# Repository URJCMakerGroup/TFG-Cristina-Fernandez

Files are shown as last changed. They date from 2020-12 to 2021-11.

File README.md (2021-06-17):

# TFG Cristina Fernández

## Project documentation in wiki: https://github.com/URJCMakerGroup/TFG-Cristina-Fernandez/wiki

## License

Hardware License: [CERN-OHL-S 2.0](cern_ohl_s_v2.txt)

Software License: [LGPL 3.0 or later](License.md)

Documentation License: [CC BY 4.0](https://creativecommons.org/licenses/by/4.0/)

licence summary

ES000021

This project has been certified as [open source hardware](https://certification.oshwa.org/es000021.html) by the [Open Source Hardware Association](https://www.oshwa.org/). 

## Organización de las carpetas:

- FreeCAD: archivo creado por FreeCAD
- Images: Imágenes de la documentación
- comps: copia del reposiorio fcad-comps de Felipe Machado
- img: imágenes de las piezas diseñadas en 3D
- src: código fuente
- step: archivo de modelo 3D formateado en STEP
- stl: archivo de modelo 3D en formato estándar que puede ser leído epor múltiples aplicaciones CAD

## Piezas:

- ### [Soporte Eje Y](https://github.com/URJCMakerGroup/TFG---Cristina---Fernandez/blob/main/src/base_class.py)

  <p align="center">
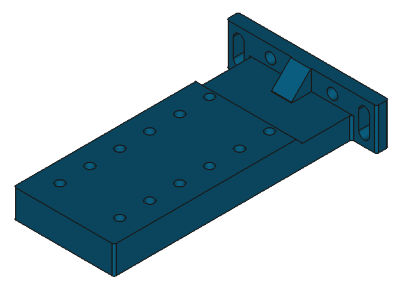
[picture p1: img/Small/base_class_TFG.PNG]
    
  </p>

- ### [Soporte motor](https://github.com/URJCMakerGroup/TFG-Cristina-Fernandez/blob/main/src/NemaMotorHolder_class.py)

<p align="center">
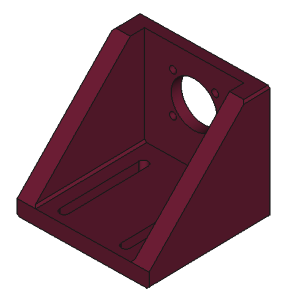
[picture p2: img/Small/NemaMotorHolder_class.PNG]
  
</p>

- ### [Soporte tuerca husillo](https://github.com/URJCMakerGroup/TFG---Cristina---Fernandez/blob/main/src/board_class.py)

<p align="center">
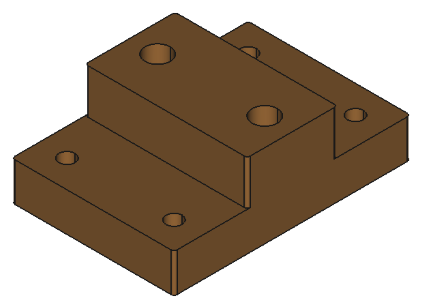
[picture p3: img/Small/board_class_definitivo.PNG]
  
</p>

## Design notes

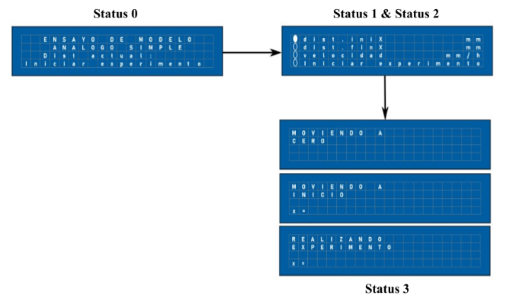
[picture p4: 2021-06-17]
Images/Small/Pantalla_LCD.PNG

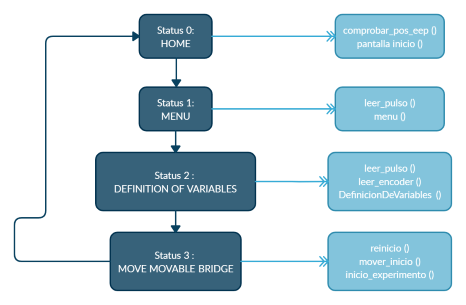
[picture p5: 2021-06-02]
Images/Small/Esquema_funcionamiento_mesa_modelado.png

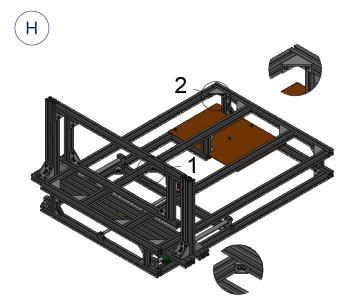
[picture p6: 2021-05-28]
Images/Small/EtapaH.PNG

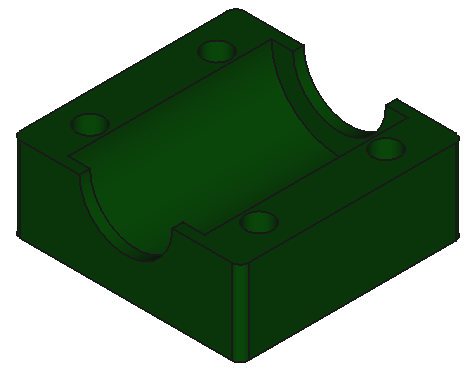
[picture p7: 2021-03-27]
img/Big/Soporte_Cojinete_inferior.PNG

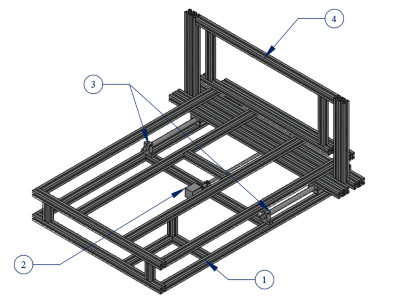
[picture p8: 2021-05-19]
Images/Small/Mesa_modelado_small.png

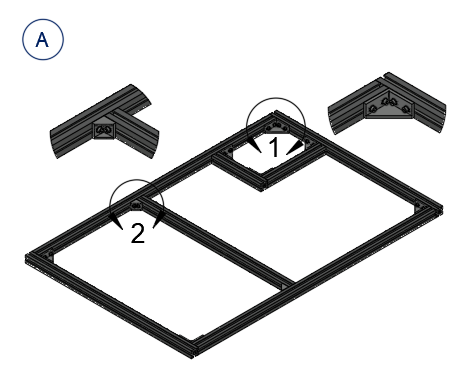
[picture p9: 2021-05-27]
Images/Big/EtapaA.PNG

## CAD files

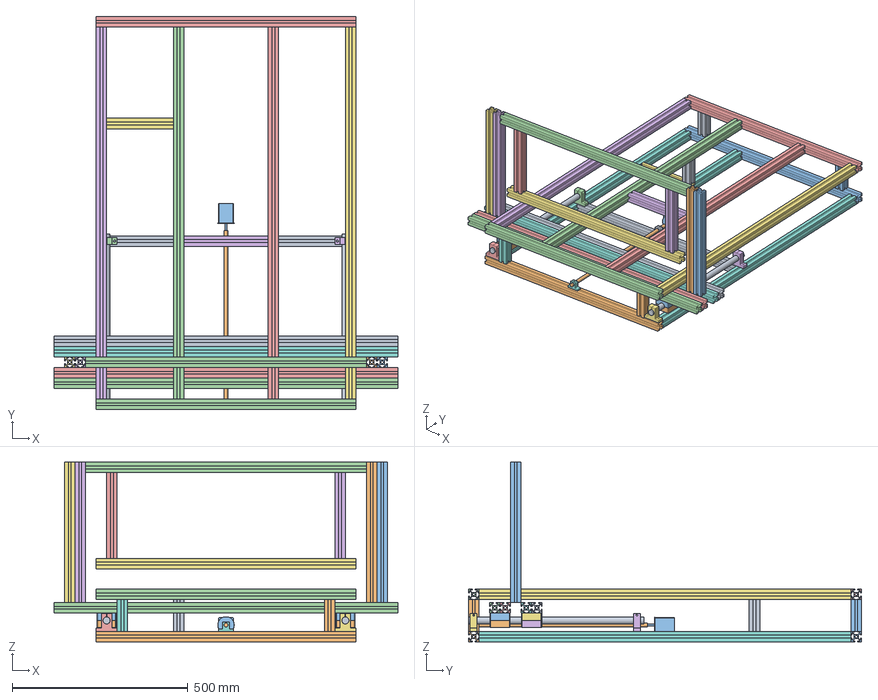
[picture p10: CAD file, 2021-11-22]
FreeCAD/geo_mesa.FCStd
980.0 x 1120.0 x 512.0 mm
travesano_int
alu_travesano_base_y0
alu_travesano_base_y1
sh__y1_xn
sh__y2_xn
sh__y1_x
sh__y2_x
alu_largo_base_xn
linbearhouse_top
linbearhouse_bot
linbearhouse_top001
linbearhouse_bot001
alu_port_vn
alu_port_vn001
alu_largo_base_x
linbearhouse_top002
linbearhouse_bot002
alu_car
alu_car001
linbearhouse_top003
linbearhouse_bot003
alu_car002
alu_car003
alu_port_vp
alu_port_vp001
top_gantry
alu_port_vp002
alu_port_vp003
alu_base_empuje
alu_v
alu_v001
alu_v002
alu_v003
alu_travesano_mesa_y0
alu_travesano_mesa_y1
alu_largo_mesa_xn
alu_largo_mesa_x
pillow__y0
pillow__y1
nema17_motor_l56
alu_largo_xn
alu_largo_x
travesano_int_sup
alu_travesano_sop_x
alu_travesano_sop_y
alu_travesano_sop_z

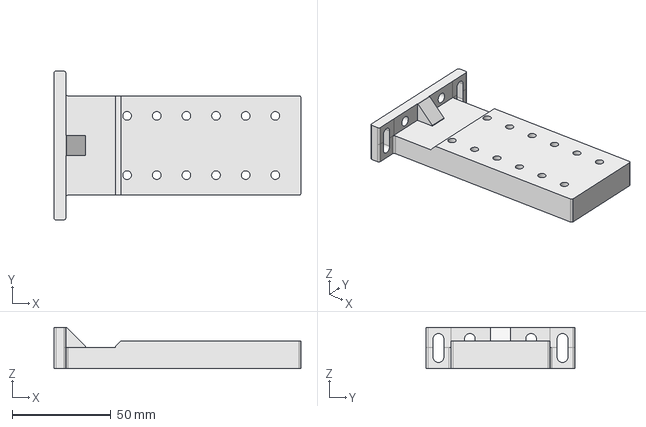
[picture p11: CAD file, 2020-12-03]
step/base_class.step
125.0 x 75.3 x 20.8 mm

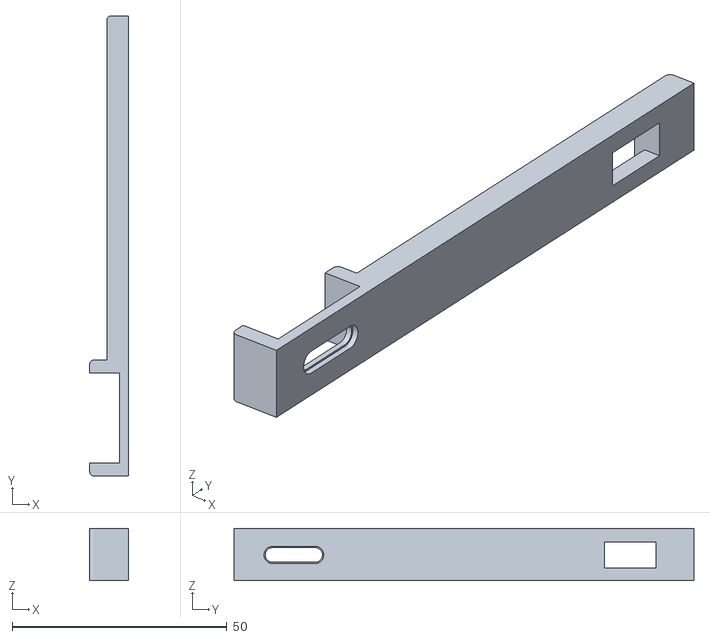
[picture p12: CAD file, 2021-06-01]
stl/Soporte_FC.stl
9.00 x 107.0 x 12.2

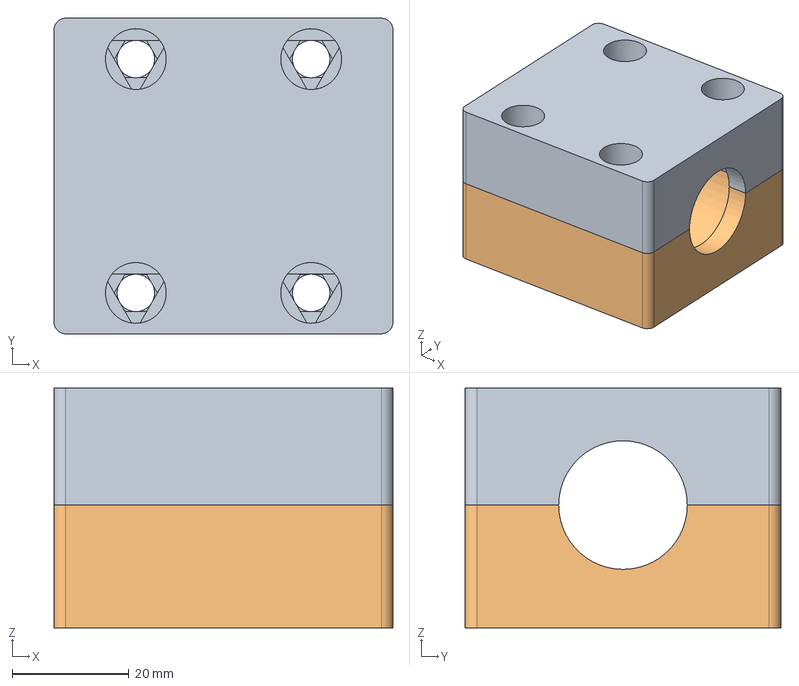
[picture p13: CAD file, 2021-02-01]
FreeCAD/SCE20UU_Pr30b_mltol_03_len58.FCStd
58.0 x 54.0 x 41.0 mm
linbearhouse_top
linbearhouse_bot

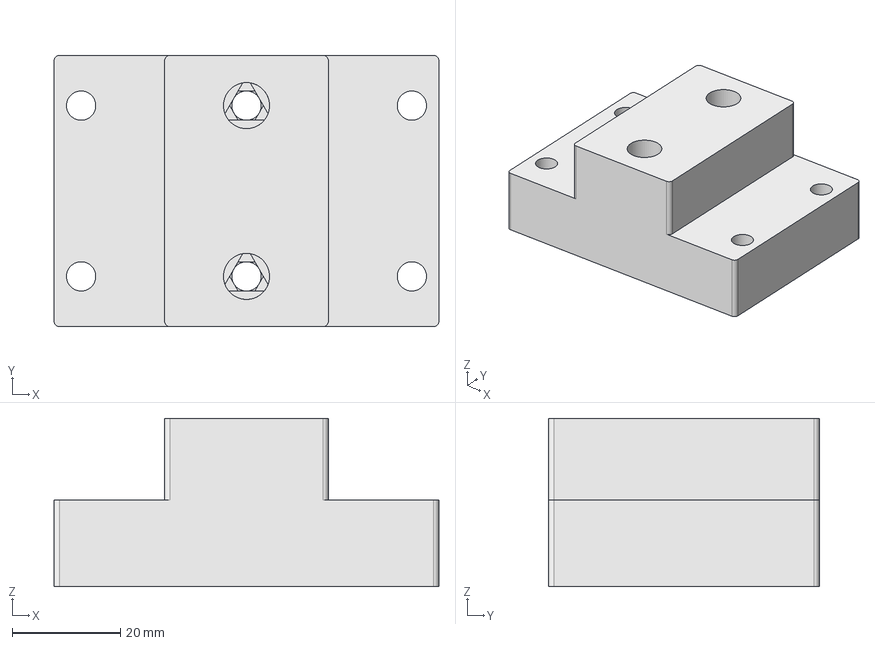
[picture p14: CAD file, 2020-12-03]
step/board_class.step
71.0 x 50.0 x 31.0 mm

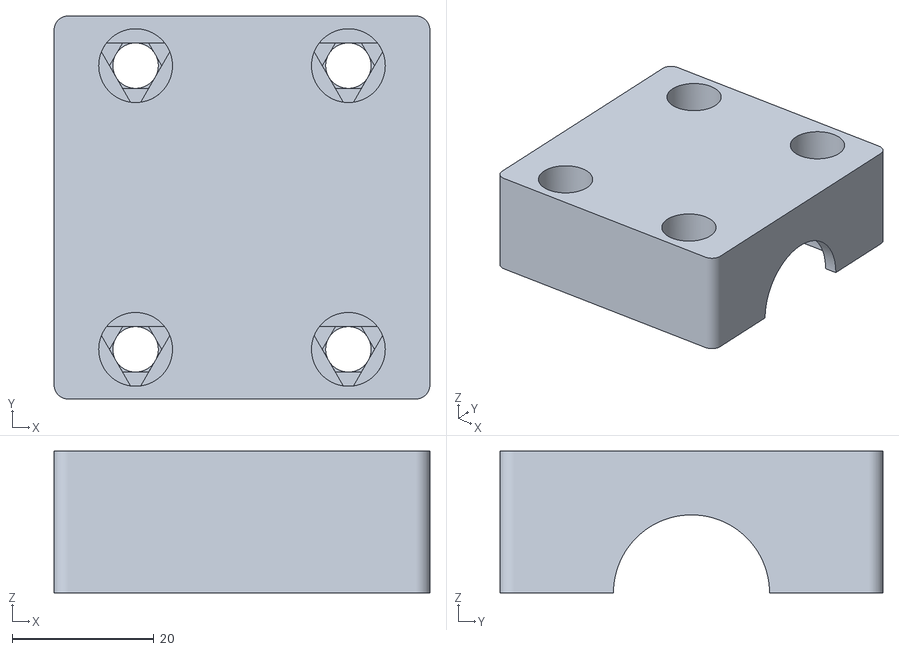
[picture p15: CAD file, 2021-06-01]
stl/linbearhouse_top.stl
53.0 x 54.0 x 20.0

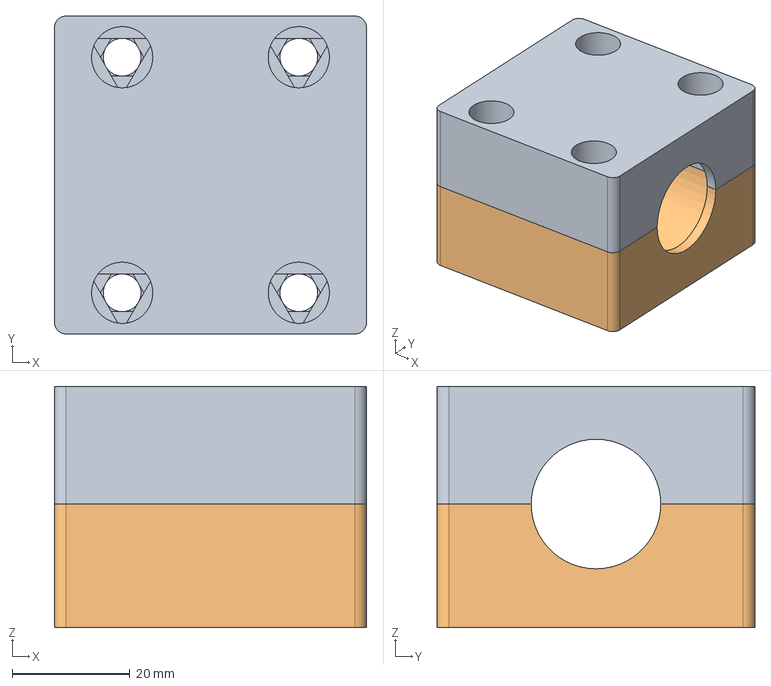
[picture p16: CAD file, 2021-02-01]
FreeCAD/SCE20UU_Pr30b_mltol_02_len58.FCStd
53.0 x 54.0 x 41.0 mm
linbearhouse_top
linbearhouse_bot

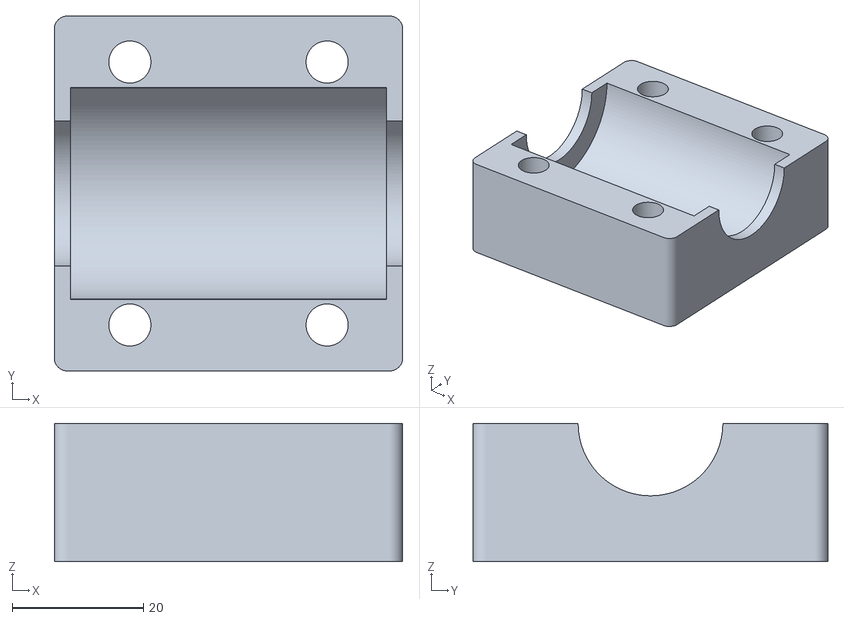
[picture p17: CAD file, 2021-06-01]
stl/linbearhouse_bot.stl
53.0 x 54.0 x 21.0

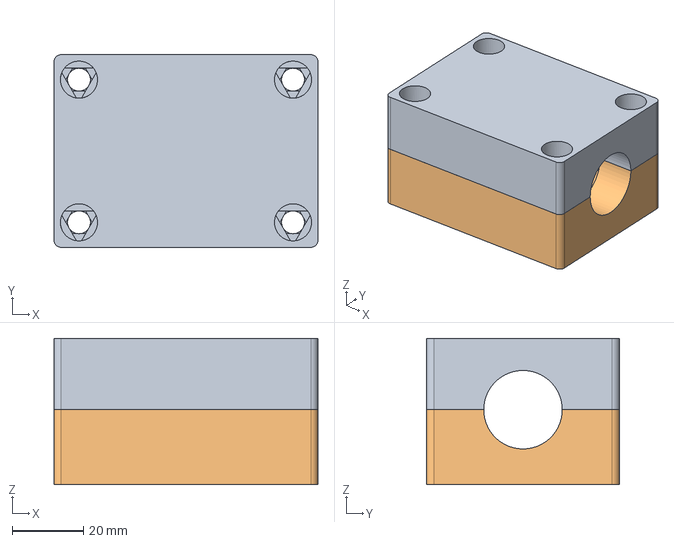
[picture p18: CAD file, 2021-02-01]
FreeCAD/SCEUU_Pr_20_mltol_04.FCStd
74.0 x 54.0 x 41.0 mm
linbearhouse_top
linbearhouse_bot

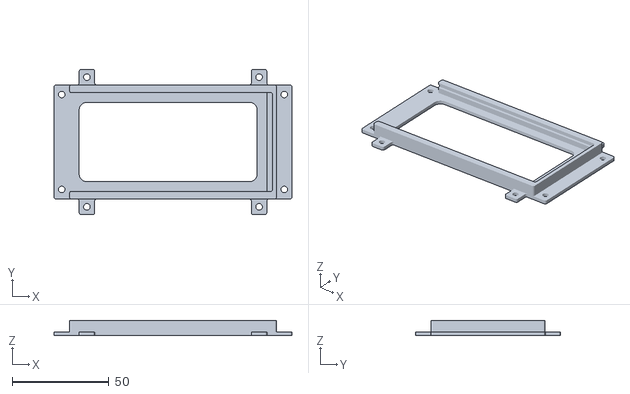
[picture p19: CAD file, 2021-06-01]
stl/bottom_coverplate.stl
123.0 x 75.0 x 8.00

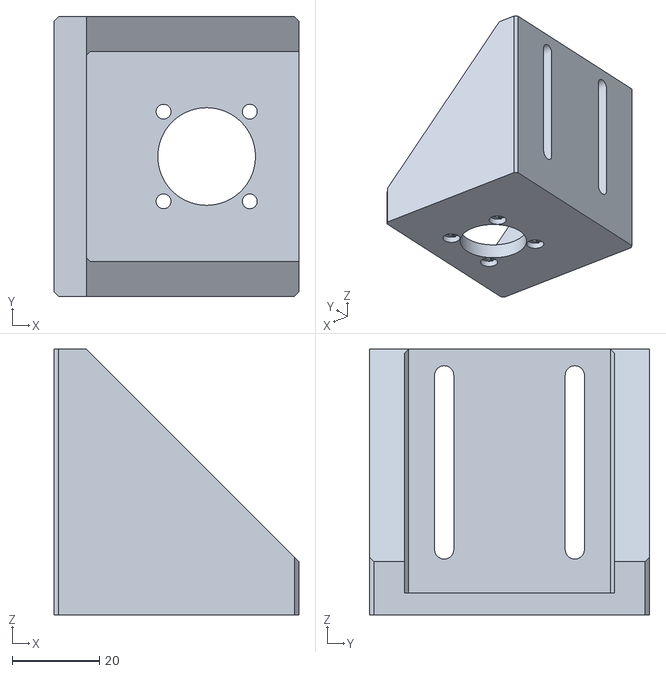
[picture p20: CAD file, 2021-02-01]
stl/NemaMotorHolder_class.stl
56.1 x 64.3 x 61.0

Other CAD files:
FreeCAD/base_class.FCStd
FreeCAD/board_class.FCStd
stl/base_class.stl
stl/board_class.stl

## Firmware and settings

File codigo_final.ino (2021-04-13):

// Biblioteca de la pantalla LCD
#include <EEPROM.h>
#include <LiquidCrystal.h>
LiquidCrystal lcd(16, 17, 23, 25, 27, 29);

//Pines de la shield
#define LCD_PINS_RS 16      // LCD control conectado a GADGETS3D  shield LCDRS
#define LCD_PINS_ENABLE 17  // LCD enable pin conectado a GADGETS3D shield LCDE
#define LCD_PINS_D4 23      // LCD signal pin, conectado a GADGETS3D shield LCD4
#define LCD_PINS_D5 25      // LCD signal pin, conectado a GADGETS3D shield LCD5
#define LCD_PINS_D6 27      // LCD signal pin, conectado a GADGETS3D shield LCD6
#define LCD_PINS_D7 29      // LCD signal pin, conectado a GADGETS3D shield LCD7
#define BTN_EN1 31          // Encoder, conectado a GADGETS3D shield S_E1
#define BTN_EN2 33          // Encoder, cconectado a GADGETS3D shield S_E2
#define BTN_ENC 35          // Encoder Click, connected to Gadgets3D shield S_EC
#define X_STEP_PIN 54       // PIN de pulsos para avanzar el motor
#define X_DIR_PIN 55        // PIN para indicar la di_Xreccion en la que debe avanzar
#define X_ENABLE_PIN 38     // PIN de lectura/escritura
#define X_MIN_PIN 3         // PIN para el fin de carrera colocado al inicio del recorrido (1: presionado (true))
#define X_MAX_PIN 2         // PIN para el fin de carrera colocado al final del recorrido

//Signos necesarios
byte empty[8] =
{
  B00000,
  B00100,
  B01010,
  B10001,
  B10001,
  B01010,
  B00100,
};
byte full[8] =
{
  B00000,
  B00100,
  B01110,
  B11111,
  B11111,
  B01110,
  B00100,
};
byte micro[8] =
{
  B00000,
  B10001,
  B10001,
  B11011,
  B10101,
  B10000,
  B10000,
};
byte arrow[8] =
{
  B00000,
  B00001,
  B00001,
  B00001,
  B01001,
  B11111,
  B01000,
};

//variables internas
bool btn_en1, btn_en2, btn_enc, btn_en1_prev, btn_en2_prev ;       //variables de lectura directa del encoder
bool fc_inic_X, fc_fin_X = true;                                   //variables de lectura de los fin de carrera
bool direccion = false;                                            //false es hacia 0 y true hacia 400
bool derecha, izquierda, pulsador = false;                         // variables de lectura del encoder interpretadas
int volatile estado, estado_ant = 0;                               // Variables del estado (valores de 0 a 5)
int fila, columna = 0;                                             // Variable de fila en la pantalla lcd
int i = 0;                                                         // contador de pulsos
int j = 0;                                                         // contador
int w = 0;                                                         // contador de micropasos medios
int w_final = 0;                                                   // numero de medios micropasos en función de la velocidad
int t_espera = 0;                                                  // tiempo de espera en función de la velocidad
int di_X, df_X = 0;                                                // variables del ensayo (distancia inicial, distancia final)en mm
int x_eeprom = 0;                                                  // variable de la posicion guardada en la eeprom
int x = 0;                                                       // posicion actual del puente movil
long x_nm = 0L;                                                     // posicion actual del puente movil en nanometros
int v, avance = 1;                                                 // variable para definir la velocidad
int L = 400;                                                       // l es la longitud del husillo, por lo que se trata de la distancia máxima que se puede llevar a cabo
int DIR_EEP = 1;                                                   // direccion de la memoria eeprom

void setup()
{
  pinMode(BTN_EN1, INPUT_PULLUP);     // Encoder 1 ¿es input o input_pullup?
  pinMode(BTN_EN2, INPUT_PULLUP);     // Encoder 2 ¿es input o input_pullup?
  pinMode(BTN_ENC, INPUT_PULLUP);     // Encoder Swith ¿es input o input_pullup?
  pinMode(X_STEP_PIN, OUTPUT);        // Pasos del motor X
  pinMode(X_DIR_PIN, OUTPUT);         // di_X direccion del motor X
  pinMode(X_ENABLE_PIN, OUTPUT);
  pinMode(X_MIN_PIN, INPUT_PULLUP);   // Fin de carrera inicio X
  pinMode(X_MAX_PIN, INPUT_PULLUP);   // Fin de carrera terminal X

  btn_en1 , btn_en1_prev = digitalRead(BTN_EN1);
  btn_en2 , btn_en2_prev = digitalRead(BTN_EN2);
  btn_enc = digitalRead(BTN_ENC);

  lcd.begin(20, 4);   // 20 columnas y 4 filas
  lcd.createChar(0, empty);   // 0: numero de carácter; empty: matriz que contiene los pixeles del carácter
  lcd.createChar(1, full);    // 1: numero de carácter; full: matriz que contiene los pixeles del carácter
  lcd.createChar(2, micro);   // 2: numero de carácter; micro: matriz que contiene los pixeles del carácter
  lcd.createChar(3, arrow);   // 3: número de carácter; arrow: matriz que contiene los pixeles del carácter
}

void leer_encoder()
{
  btn_en1 = digitalRead(BTN_EN1);
  btn_en2 = digitalRead(BTN_EN2);
  fc_inic_X = digitalRead(X_MIN_PIN);
  fc_fin_X  = digitalRead(X_MAX_PIN);
  digitalWrite(X_DIR_PIN, direccion);

  if (btn_en1 != btn_en1_prev || btn_en2 != btn_en2_prev)
  {
    if (btn_en2 == false & btn_en1 == false & btn_en2_prev == true & btn_en1_prev == false)
    {
      derecha = true;
      izquierda = false;
    }
    else if ( btn_en2 == false & btn_en1 == false & btn_en2_prev == false & btn_en1_prev == true )
    {
      derecha = false;
      izquierda = true;
    }
    else
    {
      derecha = false;
      izquierda = false;
    }
  }
  else
  {
    derecha = false;
    izquierda = false;
  }
  btn_en1_prev = btn_en1;
  btn_en2_prev = btn_en2;
}

void leer_pulso()
{
  btn_enc = digitalRead(BTN_ENC);

  if (btn_enc == false) //Detector de flanco del pulsador
  {
    i++;
  }
  if (i >= 80)
  {
    pulsador = true;
    i = 0;
    delay(200);
  }
  else
  {
    pulsador = false;
  }
}

/////////////////Estado 0: INICIO/////////////////
void comprobar_pos_eep()
{
  EEPROM.get(DIR_EEP, x_eeprom);   //Leer memoria EEPROM direccion 0
  fc_inic_X = digitalRead(X_MIN_PIN);
  fc_fin_X  = digitalRead(X_MAX_PIN);

  if (fc_inic_X == true)  // estamos en x = 0
  {
    // se puede comprobar que fc_fin_X no esta true porque sería un error
    if (x_eeprom != 0)
    {
      x_eeprom = 0;
      EEPROM.put(DIR_EEP, x_eeprom); // como la x_eeprom era incorrecta lo actualizamos con el final de carrera
    }
  }
  else if (fc_fin_X == true)  // estamos en x = l
  {
    if (x_eeprom != L)
    {
      x_eeprom = L;
      EEPROM.put(DIR_EEP, x_eeprom); // como la x_eeprom era incorrecta lo actualizamos con el final de carrera
    }
  }
  else if (x_eeprom == 0 || x_eeprom == L)  // la eeprom me dice que estoy a 0 pero el final de carrera no esta presionado (EPROMM incorrecto)
  {
    x_eeprom = -1;
    EEPROM.put(DIR_EEP, x_eeprom);
  }
}

void pantalla_inicio()
{
  lcd.clear();
  lcd.setCursor(2, 0);    // posiciona el cursor en la columna 1 fila 0
  lcd.print("ENSAYO DE MODELO");
  lcd.setCursor(3, 1);    // posiciona el cursor en la columna 1 fila 1
  lcd.print("ANALOGO SIMPLE");
  lcd.setCursor(2, 2);
  lcd.print("Dist actual:");
  lcd.print(" ");
  if (x_eeprom < 0)
  {
    lcd.print("?");
  }
  else
  {
    lcd.print(x_eeprom);
    lcd.print("mm");
  }
  lcd.setCursor(0, 3);    // posiciona el cursor en la columna 1 fila 3
  lcd.print("Iniciar Experimento");
}

/////////////////Estado 1: MENÚ/////////////////
void menu()
{
  fila, columna = 0;
  di_X = 0;
  df_X = 0;
  v = 1;
  x = x_eeprom;

  lcd.clear();
  lcd.setCursor(1, 0);
  lcd.print("dist.iniX");
  lcd.setCursor(12, 0);
  lcd.print(di_X);
  lcd.setCursor(18, 0);
  lcd.print("mm");
  lcd.setCursor(1, 1);
  lcd.print("dist.finX");
  lcd.setCursor(12, 1);
  lcd.print(df_X);
  lcd.setCursor(18, 1);
  lcd.print("mm");
  lcd.setCursor(1, 2);
  lcd.print("velocidad");
  lcd.setCursor(12, 2);
  lcd.print(v);
  lcd.setCursor(16, 2);
  lcd.print("mm/h");
  lcd.setCursor(1, 3);
  lcd.print("Iniciar experimento");
  lcd.setCursor(0, 0);
  lcd.write(byte(0));
  lcd.setCursor(0, 1);
  lcd.write(byte(0));
  lcd.setCursor(0, 2);
  lcd.write(byte(0));
  lcd.setCursor(0, 3);
  lcd.write(byte(0));
  lcd.setCursor(0, fila);
  lcd.write(byte(1));
}

/////////////////Estado 2: DEFINICIÓN DE VARIABLES/////////////////
void DefinicionDeVariables()
{
  switch (fila)//fila es la variable vertical de la pantalla, indica que variable se esta manipulando
  {
    case 0: //modificar la distancia inicial
      if (pulsador == true  and columna < 3) //columna es una variable que avanza en horizontal por la pantalla, cuando vale 0 podemos cambia en vertical con derecha o izquierda, cuando no aumentamos la variable con la que estemos trabajando
      {
        columna++;
      }
      else if (pulsador == true and columna == 3) //hay 4 opciones
      {
        columna = 0;
      }
      switch (columna)
      {
        case 0: //opción 1: seleccionar variable
          if (derecha == true )
          {
            fila = 1;
            lcd.setCursor(0, 0);
            lcd.write(byte(0));
            lcd.setCursor(0, 1);
            lcd.write(byte(1));
            lcd.setCursor(0, 2);
            lcd.write(byte(0));
            lcd.setCursor(0, 3);
            lcd.write(byte(0));
          }
          else if (izquierda == true)
          {
            fila = 3;
            lcd.setCursor(0, 0);
            lcd.write(byte(0));
            lcd.setCursor(0, 1);
            lcd.write(byte(0));
            lcd.setCursor(0, 2);
            lcd.write(byte(0));
            lcd.setCursor(0, 3);
            lcd.write(byte(1));
          }
          break;
        case 1: //opción 2: ir sumando y restando de 1 en 1
          if (derecha == true and di_X + 1 < L)
          {
            di_X = di_X + 1;
            lcd.setCursor(12, 0);
            lcd.print("   ");
            lcd.setCursor(12, 0);
            lcd.print(di_X);
          }
          else if (izquierda == true and di_X - 1 >= 0)
          {
            di_X = di_X - 1;
            lcd.setCursor(12, 0);
            lcd.print("   ");
            lcd.setCursor(12, 0);
            lcd.print(di_X);
          }
          break;
        case 2: //opción 3: ir sumando y restando de 10 en 10
          if (derecha == true and di_X + 10 < L)
          {
            di_X = di_X + 10;
            lcd.setCursor(12, 0);
            lcd.print("   ");
            lcd.setCursor(12, 0);
            lcd.print(di_X);
          }
          else if (izquierda == true and di_X - 10 >= 0)
          {
            di_X = di_X - 10;
            lcd.setCursor(12, 0);
            lcd.print("   ");
            lcd.setCursor(12, 0);
            lcd.print(di_X);
          }
          break;
        default: //opción 4: ir sumando y restando de 100 en 100
          if (derecha == true and di_X + 100 < L)
          {
            di_X = di_X + 100;
            lcd.setCursor(12, 0);
            lcd.print("   ");
            lcd.setCursor(12, 0);
            lcd.print(di_X);
          }
          else if (izquierda == true and di_X - 100 >= 0)
          {
            di_X = di_X - 100;
            lcd.setCursor(12, 0);
            lcd.print("   ");
            lcd.setCursor(12, 0);
            lcd.print(di_X);
          }
          break;
      }
      break;
    case 1: //modificar la distancia final
      if (pulsador == true  and columna < 3) //columna es una variable que avanza en horizontal por la pantalla, cuando vale 0 podemos cambia en vertical con derecha o izquierda, cuando no aumentamos la variable con la que estemos trabajando
      {
        columna++;
      }
      else if (pulsador == true and columna == 3)
      {
        columna = 0;
      }
      switch (columna)
      {
        case 0: //opción 1: seleccionar variable
          if (derecha == true )
          {
            fila = 2;
            lcd.setCursor(0, 0);
            lcd.write(byte(0));
            lcd.setCursor(0, 1);
            lcd.write(byte(0));
            lcd.setCursor(0, 2);
            lcd.write(byte(1));
            lcd.setCursor(0, 3);
            lcd.write(byte(0));
          }
          else if (izquierda == true)
          {
            fila = 0;
            lcd.setCursor(0, 0);
            lcd.write(byte(1));
            lcd.setCursor(0, 1);
            lcd.write(byte(0));
            lcd.setCursor(0, 2);
            lcd.write(byte(0));
            lcd.setCursor(0, 3);
            lcd.write(byte(0));
          }
          break;
        case 1: //opción 2: ir sumando y restando de 1 en 1
          if (derecha == true and df_X + 1 < L)
          {
            df_X = df_X + 1;
            lcd.setCursor(12, 1);
            lcd.print("   ");
            lcd.setCursor(12, 1);
            lcd.print(df_X);
          }
          else if (izquierda == true and df_X - 1 >= 0)
          {
            df_X = df_X - 1;
            lcd.setCursor(12, 1);
            lcd.print("   ");
            lcd.setCursor(12, 1);
            lcd.print(df_X);
          }
          break;
        case 2: //opción 3: ir sumando y restando de 10 en 10
          if (derecha == true and df_X + 10 < L)
          {
            df_X = df_X + 10;
            lcd.setCursor(12, 1);
            lcd.print("   ");
            lcd.setCursor(12, 1);
            lcd.print(df_X);
          }
          else if (izquierda == true and df_X - 10 >= 0)
          {
            df_X = df_X - 10;
            lcd.setCursor(12, 1);
            lcd.print("   ");
            lcd.setCursor(12, 1);
            lcd.print(df_X);
          }
          break;
        default://opción 4: ir sumando y restando de 100 en 100
          if (derecha == true and df_X + 100 < L)
          {
            df_X = df_X + 100;
            lcd.setCursor(12, 1);
            lcd.print("   ");
            lcd.setCursor(12, 1);
            lcd.print(df_X);
          }
          else if (izquierda == true and df_X - 100 >= 0)
          {
            df_X = df_X - 100;
            lcd.setCursor(12, 1);
            lcd.print("   ");
            lcd.setCursor(12, 1);
            lcd.print(df_X);
          }
          break;
      }
      break;
    case 2: //modificar la velocidad
      if (pulsador == true  and columna < 1) //columna es una variable que avanza en horizontal por la pantalla, cuando vale 0 podemos cambia en vertical con derecha o izquierda, cuando no aumentamos la variable con la que estemos trabajando
      {
        columna++;
      }
      else if (pulsador == true and columna == 1) //hay 2 opciones
      {
        columna = 0;
      }
      switch (columna)
      {
        case 0: //opción 1: seleccionar variable
          if (derecha == true )
          {
            fila = 3;
            lcd.setCursor(0, 0);
            lcd.write(byte(0));
            lcd.setCursor(0, 1);
            lcd.write(byte(0));
            lcd.setCursor(0, 2);
            lcd.write(byte(0));
            lcd.setCursor(0, 3);
            lcd.write(byte(1));
          }
          else if (izquierda == true)
          {
            fila = 1;
            lcd.setCursor(0, 0);
            lcd.write(byte(0));
            lcd.setCursor(0, 1);
            lcd.write(byte(1));
            lcd.setCursor(0, 2);
            lcd.write(byte(0));
            lcd.setCursor(0, 3);
            lcd.write(byte(0));
          }
          break;
        default: //opción 2: modificar la velocidad de 1 en 1 o de 10 en 10 en función de la velocidad
          if (izquierda == true)
          {
            if (v <= 10 and v > 0)
            {
              v = v - 1;
              lcd.setCursor(12, 2);
              lcd.print("   ");
              lcd.setCursor(12, 2);
              lcd.print(v);
            }
            else if (v > 10)
            {
              v = v - 10;
              lcd.setCursor(12, 2);
              lcd.print("   ");
              lcd.setCursor(12, 2);
              lcd.print(v);
            }
          }
          else if (derecha == true)
          {
            if (v < 10)
            {
              v = v + 1;
              lcd.setCursor(12, 2);
              lcd.print("   ");
              lcd.setCursor(12, 2);
              lcd.print(v);
            }
            else if (v >= 10 and v < 100)
            {
              v = v + 10;
              lcd.setCursor(12, 2);
              lcd.print("   ");
              lcd.setCursor(12, 2);
              lcd.print(v);
            }
          }
          break;
      }
      break;
    default: //iniciar experimento
      if (pulsador == true)
      {
        estado = 3;
        //        lcd.clear();
        //        lcd.setCursor(1, 0);
        //        lcd.print("PREPARANDO");
        //        lcd.setCursor(1, 1);
        //        lcd.print("EXPERIMENTO...");
        //        delay(5000);
      }
      else if (derecha == true )
      {
        fila = 0;
        columna = 0;
        lcd.setCursor(0, 0);
        lcd.write(byte(1));
        lcd.setCursor(0, 1);
        lcd.write(byte(0));
        lcd.setCursor(0, 2);
        lcd.write(byte(0));
        lcd.setCursor(0, 3);
        lcd.write(byte(0));
      }
      else if (izquierda == true)
      {
        fila = 2;
        columna = 0;
        lcd.setCursor(0, 0);
        lcd.write(byte(0));
        lcd.setCursor(0, 1);
        lcd.write(byte(0));
        lcd.setCursor(0, 2);
        lcd.write(byte(1));
        lcd.setCursor(0, 3);
        lcd.write(byte(0));
      }
      break;
  }
}

/////////////////Estado 3: MOVER PUENTE MÓVIL/////////////////
void reinicio()
{
  lcd.clear();
  lcd.setCursor(1, 0);
  lcd.print("MOVIENDO A");
  lcd.setCursor(1, 1);
  lcd.print("CERO");

  direccion = false;
  digitalWrite(X_DIR_PIN, direccion);
  while (fc_inic_X == false)
  {
    for (int w = 0; w < 32; w++)
    {
      fc_inic_X = digitalRead(X_MIN_PIN);
      fc_fin_X  = digitalRead(X_MAX_PIN);
      if (fc_fin_X == false and fc_inic_X == false)
      {
        if (w % 2 == 0) //0: par 1:impar
        {
          digitalWrite(X_STEP_PIN, HIGH);
          delayMicroseconds(6);
        }
        else
        {
          digitalWrite(X_STEP_PIN, LOW);
          delayMicroseconds(6);
        }
      }
      else
      {
        digitalWrite(X_STEP_PIN, LOW);
      }
    }
  }
  x = 0;
}

void mover_inicio()
{
  lcd.clear();
  lcd.setCursor(1, 0);
  lcd.print("MOVIENDO A");
  lcd.setCursor(1, 1);
  lcd.print("INICIO");
  lcd.setCursor(1, 2);
  lcd.print("x =");
  lcd.print(" ");

  //x = x_eeprom;
  x_nm = x * 1000000L; //calculo en nanometros, por 1 millon

  if (x < di_X)
  {
    direccion = true;
    digitalWrite(X_DIR_PIN, direccion);
    while (x < di_X)
    {
      for (int w = 0; w < 32; w++)
      {
        fc_inic_X = digitalRead(X_MIN_PIN);
        fc_fin_X  = digitalRead(X_MAX_PIN);
        if (fc_fin_X == false)
        {
          if (w % 2 == 0) //0: par 1:impar
          {
            digitalWrite(X_STEP_PIN, HIGH);
            delayMicroseconds(6);
          }
          else
          {
            digitalWrite(X_STEP_PIN, LOW);
            delayMicroseconds(6);
          }
        }
        else
        {
          digitalWrite(X_STEP_PIN, LOW);
        }
      }
      x_nm = x_nm + 147;
      x = x_nm / 1000000;
      lcd.setCursor(6, 2);
      lcd.print(x);
      lcd.print(" mm");
    }
  }
  else
  {
    direccion = false;
    digitalWrite(X_DIR_PIN, direccion);
    while (x > di_X)
    {
      for (int w = 0; w < 32; w++)
      {
        fc_inic_X = digitalRead(X_MIN_PIN);
        fc_fin_X  = digitalRead(X_MAX_PIN);
        if (fc_inic_X == false)
        {
          if (w % 2 == 0) //0: par 1:impar
          {
            digitalWrite(X_STEP_PIN, HIGH);
            delayMicroseconds(6);
          }
          else
          {
            digitalWrite(X_STEP_PIN, LOW);
            delayMicroseconds(6);
          }
        }
        else
        {
          digitalWrite(X_STEP_PIN, LOW);
        }
      }
      x_nm = x_nm - 147;
      x = x_nm / 1000000;
      lcd.setCursor(6, 2);  //columna 6, fila 2
      lcd.print(x);
      lcd.print(" mm");
    }
  }
  x = di_X;
}
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
void loop ()
{
  switch (estado)
  {
    case 0: // Estado inicial
      comprobar_pos_eep();
      pantalla_inicio();
      estado = 1;
      break;
    case 1: // esperar al pulsador sin hacer nada
      leer_pulso();
      if (pulsador == true)
      {
        menu();
        estado = 2;
      }
      break;
    case 2:
      leer_pulso();
      leer_encoder();
      DefinicionDeVariables();
      break;
    case 3:
      x_eeprom = -1;
      EEPROM.put(DIR_EEP, x_eeprom);
      if (x_eeprom < 0)
      {
        reinicio();
        if (x_eeprom != di_X)
        {
          mover_inicio();
          inicio_experimento();
          estado = 0;
        }
        else
        {
          inicio_experimento();
          estado = 0;
        }
      }
      else
      {
        if (x_eeprom != di_X)
        {
          mover_inicio();
          inicio_experimento();
          estado = 0;
        }
        else
        {
          inicio_experimento();
          estado = 0;
        }
      }
      break;
    default:
      break;
  }
}

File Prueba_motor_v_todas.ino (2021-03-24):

#define X_STEP_PIN 54       // PIN de pulsos para avanzar el motor
#define X_DIR_PIN 55        // PIN para indicar la di_Xreccion en la que debe avanzar
#define X_ENABLE_PIN 38
#define X_MIN_PIN 3         // PIN para el fin de carrera colocado al inicio del recorrido
#define X_MAX_PIN 2         // PIN para el fin de carrera colocado al final del recorrido

bool fc_inic_X, fc_fin_X = true; //variables de lectura de los fin de carrera
bool direccion = false; 
int i, j, w = 0 ; // diversos contadores
int v = 30;

void setup() {
  // put your setup code here, to run once:
  pinMode(X_STEP_PIN, OUTPUT);      // Pasos del motor X
  pinMode(X_DIR_PIN, OUTPUT);       // di_X  direccion del motor X
  pinMode(X_ENABLE_PIN, OUTPUT);
  pinMode(X_MIN_PIN, INPUT_PULLUP);        // Fin de carrera inicio X
  pinMode(X_MAX_PIN, INPUT_PULLUP);        // Fin de carrera terminal X

  digitalWrite(X_ENABLE_PIN, LOW);
}

void loop() 
{
switch (v)
  {
    case 1: // velocidad = 1 mm/h
      for (int i = 0; i < 2544; i++)
      {
        fc_inic_X = digitalRead(X_MIN_PIN);
        fc_fin_X  = digitalRead(X_MAX_PIN);
        if (fc_fin_X == false and fc_inic_X == false)
        {
          if (i < 32)
          {
            digitalWrite(X_STEP_PIN, HIGH);
            delayMicroseconds(208);
            digitalWrite(X_STEP_PIN, LOW);
            delayMicroseconds(208);
          }
          else
          {
            digitalWrite(X_STEP_PIN,LOW);
            delayMicroseconds(208);
          }
        }
        else
        {
          digitalWrite(X_STEP_PIN, LOW);
        }
      }
      break;
    case 2:
      for (int i = 0; i < 1272; i++)
      {
        fc_inic_X = digitalRead(X_MIN_PIN);
        fc_fin_X  = digitalRead(X_MAX_PIN);
        if (fc_fin_X == false and fc_inic_X == false)
        {
          if (i < 32)
          {
            digitalWrite(X_STEP_PIN, HIGH);
            delayMicroseconds(208);
            digitalWrite(X_STEP_PIN, LOW);
            delayMicroseconds(208);
          }
          else
          {
            digitalWrite(X_STEP_PIN,LOW);
            delayMicroseconds(208);
          }
        }
        else
        {
          digitalWrite(X_STEP_PIN, LOW);
        }
      }
      break;
    case 3:
      for (int i = 0; i < 848; i++)
      {
        fc_inic_X = digitalRead(X_MIN_PIN);
        fc_fin_X  = digitalRead(X_MAX_PIN);
        if (fc_fin_X == false and fc_inic_X == false)
        {
          if (i < 32)
          {
            digitalWrite(X_STEP_PIN, HIGH);
            delayMicroseconds(208);
            digitalWrite(X_STEP_PIN, LOW);
            delayMicroseconds(208);
          }
          else
          {
            digitalWrite(X_STEP_PIN,LOW);
            delayMicroseconds(208);
          }
        }
        else
        {
          digitalWrite(X_STEP_PIN, LOW);
        }
      }
      break;
    case 4:
      for (int i = 0; i < 636; i++)
      {
        fc_inic_X = digitalRead(X_MIN_PIN);
        fc_fin_X  = digitalRead(X_MAX_PIN);
        if (fc_fin_X == false and fc_inic_X == false)
        {
          if (i < 32)
          {
            digitalWrite(X_STEP_PIN, HIGH);
            delayMicroseconds(208);
            digitalWrite(X_STEP_PIN, LOW);
            delayMicroseconds(208);
          }
          else
          {
            digitalWrite(X_STEP_PIN,LOW);
            delayMicroseconds(208);
          }
        }
        else
        {
          digitalWrite(X_STEP_PIN, LOW);
        }
      }
      break;
    case 5:
      for (int i = 0; i < 508; i++)
      {
        fc_inic_X = digitalRead(X_MIN_PIN);
        fc_fin_X  = digitalRead(X_MAX_PIN);
        if (fc_fin_X == false and fc_inic_X == false)
        {
          if (i < 32)
          {
            digitalWrite(X_STEP_PIN, HIGH);
            delayMicroseconds(208);
            digitalWrite(X_STEP_PIN, LOW);
            delayMicroseconds(208);
          }
          else
          {
            digitalWrite(X_STEP_PIN,LOW);
            delayMicroseconds(208);
          }
        }
        else
        {
          digitalWrite(X_STEP_PIN, LOW);
        }
      }
      break;
    case 6:
      for (int i = 0; i < 424; i++)
      {
        fc_inic_X = digitalRead(X_MIN_PIN);
        fc_fin_X  = digitalRead(X_MAX_PIN);
        if (fc_fin_X == false and fc_inic_X == false)
        {
          if (i < 32)
          {
            digitalWrite(X_STEP_PIN, HIGH);
            delayMicroseconds(208);
            digitalWrite(X_STEP_PIN, LOW);
            delayMicroseconds(208);
          }
          else
          {
            digitalWrite(X_STEP_PIN,LOW);
            delayMicroseconds(208);
          }
        }
        else
        {
          digitalWrite(X_STEP_PIN, LOW);
        }
      }
      break;
    case 7:
      for (int i = 0; i < 362; i++)
      {
        fc_inic_X = digitalRead(X_MIN_PIN);
        fc_fin_X  = digitalRead(X_MAX_PIN);
        if (fc_fin_X == false and fc_inic_X == false)
        {
          if (i < 32)
          {
            digitalWrite(X_STEP_PIN, HIGH);
            delayMicroseconds(208);
            digitalWrite(X_STEP_PIN, LOW);
            delayMicroseconds(208);
          }
          else
          {
            digitalWrite(X_STEP_PIN,LOW);
            delayMicroseconds(208);
          }
        }
        else
        {
          digitalWrite(X_STEP_PIN, LOW);
        }
      }
      break;
    case 8:
      for (int i = 0; i < 318; i++)
      {
        fc_inic_X = digitalRead(X_MIN_PIN);
        fc_fin_X  = digitalRead(X_MAX_PIN);
        if (fc_fin_X == false and fc_inic_X == false)
        {
          if (i < 32)
          {
            digitalWrite(X_STEP_PIN, HIGH);
            delayMicroseconds(208);
            digitalWrite(X_STEP_PIN, LOW);
            delayMicroseconds(208);
          }
          else
          {
            digitalWrite(X_STEP_PIN,LOW);
            delayMicroseconds(208);
          }
        }
        else
        {
          digitalWrite(X_STEP_PIN, LOW);
        }
      }
      break;
    case 9:
      for (int i = 0; i < 282; i++)
      {
        fc_inic_X = digitalRead(X_MIN_PIN);
        fc_fin_X  = digitalRead(X_MAX_PIN);
        if (fc_fin_X == false and fc_inic_X == false)
        {
          if (i < 32)
          {
            digitalWrite(X_STEP_PIN, HIGH);
            delayMicroseconds(208);
            digitalWrite(X_STEP_PIN, LOW);
            delayMicroseconds(208);
          }
          else
          {
            digitalWrite(X_STEP_PIN,LOW);
            delayMicroseconds(208);
          }
        }
        else
        {
          digitalWrite(X_STEP_PIN, LOW);
        }
      }
      break;
    case 10:
      for (int i = 0; i < 254; i++)
      {
        fc_inic_X = digitalRead(X_MIN_PIN);
        fc_fin_X  = digitalRead(X_MAX_PIN);
        if (fc_fin_X == false and fc_inic_X == false)
        {
          if (i < 32)
          {
            digitalWrite(X_STEP_PIN, HIGH);
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

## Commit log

2021-01-29 Add Linear bearing housing for SCEUU 20 tol 0.4
    MLTOL was too large: 0.35 -> making the diameter tolerance 0.7
    That was too much, now we have diameter tolerance of 0.4 to check
    [SCEUU_Pr_20_mltol_04.FCStd]
2021-01-30 Add SCE20UU housing with 30mm bolt separation
    This is the good one to have it with the 30mm profiles
    Tolerance of the bearing diameter has been reduced to 0.3mm
    The total length has been enlarged from 53mm to 58mm
    [SCE20UU_Pr30b_mltol_03_len58.FCStd]
2021-02-01 Add linear bearing housing with tolerance 0.2
    MLTOL = kparts.MTOL/2. -0.1
    [SCE20UU_Pr30b_mltol_02_len58.FCStd]
2021-02-14 Finished piece soporte arduino
2021-02-27 Aluminum bracket code
2021-06-01 Replace the stl's archives
    [NemaMotorHolder_class.stl, NemaMotorHolder_new_class.stl, base_class.stl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]
2021-06-01 New files
    [NemaMotorHolder_class.stl, NemaMotorHolder_class_mal.stl, NemaMotorHolder_new_class.stl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]
2021-06-01 Delated old files
    [NemaMotorHolder_class_mal.stl, NemaMotorHolder_new_class.stl, base_new_class.stl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]
2021-11-22 Add the generated FreeCAD file of entire design
    Also exported to STEP
    [geo_mesa.FCStd]
